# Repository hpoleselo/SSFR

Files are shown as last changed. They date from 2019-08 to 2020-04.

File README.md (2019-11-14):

# Stationary Spinning Follower Robot
A robot that uses fiducial markers (ArUco) to obtain the relative position to the marker and adjusts its position using PID control to follow the moving marker. You can find also separately the modelling of a DC motor which we used on SSFR.

setup

## Installation
Get the Raspberry Pi Ubuntu Mate Installation for your Rpi:
https://ubuntu-mate.org/download/

Install git:

``` $ sudo apt-get install git ```

Install OpenCV with Python in the Rpi in order to make use of the ArUco library:

``` $ sudo apt-get install python-opencv ```

Clone the repository anywhere you want:

``` $ git clone https://github.com/hpoleselo/SSFR.git ```

## Usage

If you want to check how we retrieve the model for the control, check the folder ``` PlantModel ``` with MATLAB.

## Lessons Learned

Check the file [linque] to the next time we decide building a robot from scratch...

## Authors

* **Henrique Poleselo** - [hpoleselo](https://github.com/hpoleselo)
* **Jesse de Oliveira Santana Alves** - [Jessalves11](https://github.com/Jessalves11)
* **Luis Gustavo Nunes Christensen** - [Goustaf](https://github.com/goustaf)

## Professor

**Humberto Xavier de Araujo**

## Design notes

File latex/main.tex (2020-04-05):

\documentclass{article}

\usepackage{arxiv}

\usepackage[utf8]{inputenc} % allow utf-8 input
\usepackage[T1]{fontenc}    % use 8-bit T1 fonts
\usepackage{hyperref}       % hyperlinks
\usepackage{url}            % simple URL typesetting
\usepackage{booktabs}       % professional-quality tables
\usepackage{amsfonts}       % blackboard math symbols
\usepackage{nicefrac}       % compact symbols for 1/2, etc.
\usepackage{microtype}      % microtypography
\usepackage{lipsum}
\usepackage{amsmath}
\usepackage{graphicx}

% Joop Que Recomendou
\geometry{a4paper,right=2.5cm,left=2.5cm,top=3.5cm,bottom=3cm} % margens
\setlength{\parindent}{1cm} % espaçamento do parágrafo
\usepackage{geometry} % configurar layout da página
\usepackage{setspace} % configurar o espaçamento de linhas
\usepackage{indentfirst} % alinhamento do texto, parágrafos

\graphicspath{ {./images/} }
\RequirePackage{amsmath,amsthm,amssymb,hyperref} % Math 
\RequirePackage[brazilian]{babel} % Portugûes

\title{Controle e Modelagem de um Motor de Corrente Contínua - Trabalho de Modelagem e Análise de Sistemas Dinâmicos}

\author{
  Docente: Humberto Xavier de Araújo \\
  \And
  Henrique Nunes Poleselo \\
  %% examples of more authors
   \And
 Jesse de O. S. Alves \\
  \And
  Luis Gustavo Christensen
  %% \AND
  %% Coauthor \\
  %% Affiliation \\
  %% Address \\
  %% \texttt{email} \\
  %% \And
  %% Coauthor \\
  %% Affiliation \\
  %% Address \\
  %% \texttt{email} \\
  %% \And
  %% Coauthor \\
  %% Affiliation \\
  %% Address \\
  %% \texttt{email} \\
}
\begin{document}
\maketitle

\section{Introdução}

O ato de medir a velocidade de uma roda, chamado de odometria, é essencial no campo da robótica móvel, principalmente nos dias atuais, onde o poder de processamento tem aumentado, e portanto, possibilitando a fusão de sensores (odometria com visão computacional, por exemplo) para implementação de controladores mais complexos. Dito isso, a aplicação em questão trata da modelagem e controle de velocidade de um motor de corrente contínua que é acoplado a uma roda. Neste relatório serão apresentados alguns métodos utilizados para a obtenção do modelo caixa preta e o processo de elaboração do controlador.
Deste modo, este trabalho está separado em 8 seções onde cada seção está dividida da seguinte forma: na seção 2 serão mencionados os objetivos do projeto, na seção 3 o protótipo é apresentado. Na seção 4 o processo de modelagem é explicitado, na seção 5, o projeto do controlador do sistema. Na seção 6 os resultados obtidos serão apresentados e em seguida as conclusões do projeto na seção 7. 

\section{Objetivos}
Apesar de utilizar-se os métodos de obtenção de modelo caixa preta, é sabido que a variável velocidade angular de um motor de corrente contínua é um sistema estável. Portanto, o sistema naturalmente chegará ao seu regime permanente para uma entrada degrau. O objetivo da aplicação em questão é fazer com que o motor de corrente contínua atinja esta velocidade angular com um tempo menor utilizando controle PID para reduzir o erro consequentemente.

\section{Descrição do problema}
Para a construção do protótipo utilizou-se apenas um motor de corrente contínua, um Arduino UNO que possui o microcontrolador ATMega328, um sensor (LM393) infravermelho com um fototransistor que gera uma interrupção, um disco de \textit{encoder} e uma ponte H para gerar a corrente necessária para o controle do motor.
A alimentação do motor é dada pela ponte H que recebe um sinal de PWM (\textit{Pulse Width Modulation}) do Arduino e o transmite para o motor com a corrente necessária.
Para obter as curvas da velocidade angular do motor, o disco de \textit{encoder} foi acoplado ao eixo do motor e o sensor infravermelho foi posicionado de modo que este detectasse e gerasse uma interrupção toda vez em que o feixe de onda eletromagnética atravessasse um buraco do disco. Dessa forma, é possível medir a frequência com que o disco gira e utilizando o raio da roda determinar a velocidade angular do mesmo ao longo do tempo. Essas medições realizadas com o sensor foram validadas através de uma marcação na roda e determinação da velocidade linear que posteriormente foi dividida pelo raio da roda, e percebeu-se que o sensor apresenta distorções para rotações altas (próximas a 120 bits de PWM), além de apresentar medições relativamente ruidosas.

Para a leitura da velocidade, fez-se como descrito acima e a montagem pode ser vista na figura 1:
\begin{center}
\centering
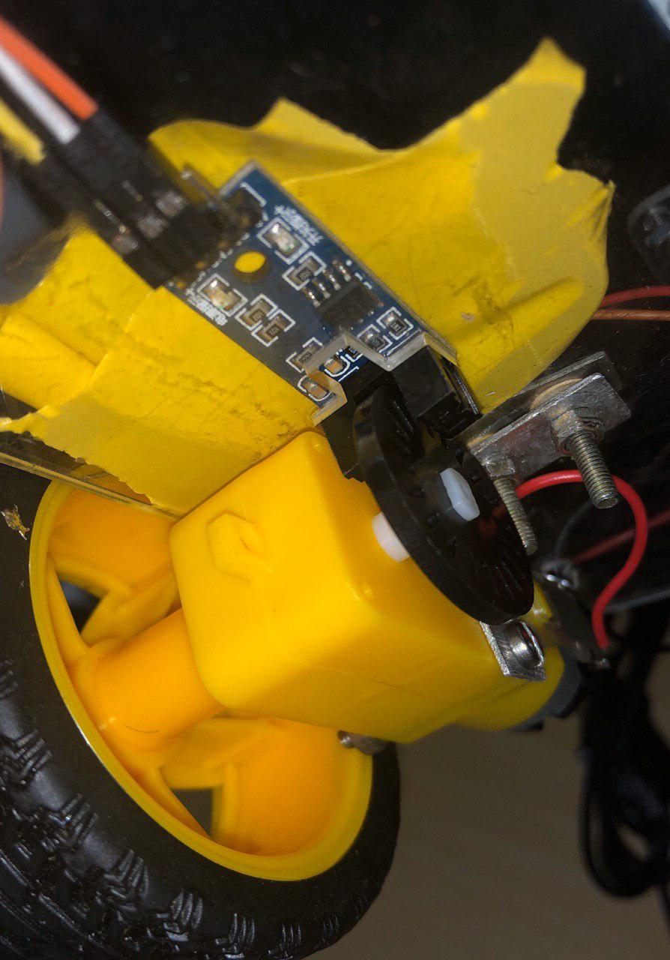
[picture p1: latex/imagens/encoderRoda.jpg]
  
  
  \caption{Figura 1: Montagem para leitura da velocidade da roda.}
\end{center}

As rodas foram acopladas à uma base podendo servir futuramente como um robô. Na seção 4 a modelagem do motor é feita com o robô suspenso, portanto desprezando atrito dinâmico e considerando apenas o atrito estático do próprio motor e da roda. A montagem final pode ser vista na figura 2.

\begin{center}
\centering
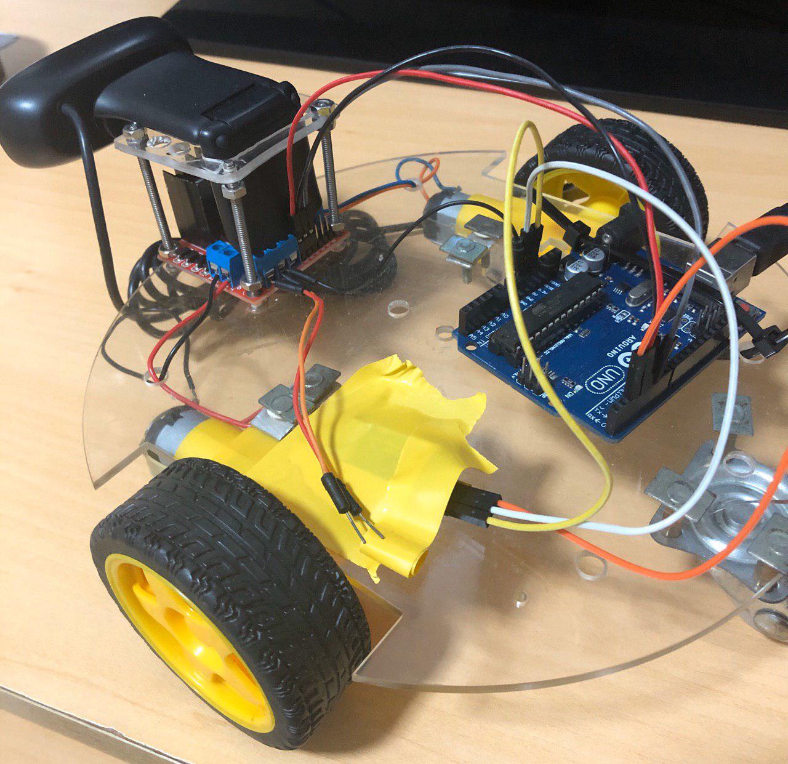
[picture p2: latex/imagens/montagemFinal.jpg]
  
  
  \caption{Figura 2: Protótipo montado.}
\end{center}

\section{Modelagem}

\subsection{Modelo Estático}
Para ter um bom ponto de partida parta a modelagem do sistema, obteve-se a curva do comportamento estático do sistema. Tal curva é importante para determinar a faixa de valores de PWM na qual o sistema responda da forma mais linear, facilitando assim o controle do processo.
Para determinar qual a faixa de operação do PWM, foi aplicado por meio do microcontrolador diferentes valores (de 0 a 255, faixa de 8 bits) e analisou-se que a zona morta do motor se situava na faixa de 0 a 60 bits do PWM, portanto, assumiu-se que a faixa de operação para o controlador seria de no mínimo 6O bits do PWM. O modelo estático foi proposto com a variação do PWM entre 75 e 255 bits pois é a faixa em que o motor opera com segurança.

\begin{center}
\centering
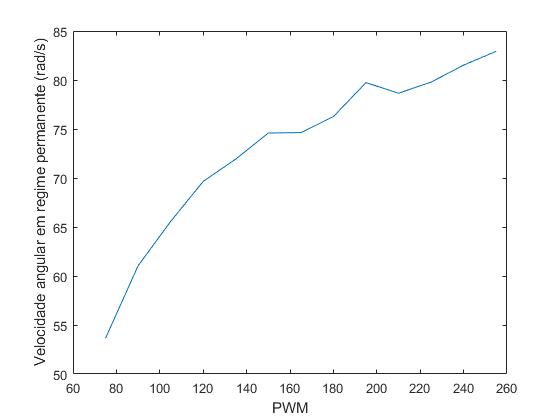
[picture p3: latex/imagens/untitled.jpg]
  
  
  \caption{Figura 3: Modelo estático do motor de corrente contínua.}
\end{center}

A partir da figura 3 é possível notar que na faixa entre 90 e 145 PWM há um comportamento aproximadamente linear, logo é desejável trabalhar com valores contidos nesse intervalo.

\subsection{Modelo Dinâmico}
O modelo dinâmico apresenta a relação entre a entrada e a saída do sistema no regime transitório e permanente. Tal comportamento é obtido a partir de uma entrada degrau, que na aplicação é um "nível DC" do PWM, portanto tensão.
Assim como no modelo estático, a entrada será o valor do PWM e a saída será a velocidade angular da roda. Foi escolhido 120 como valor de PWM já que este se encontra no intervalo em que o sistema mostrou um comportamento linear no modelo estático. Na Figura 4, utilizando a lógica mencionada na seção 3, obteve-se a velocidade angular instantânea da roda com um tempo de amostragem de $50ms$.

\begin{center}
\centering
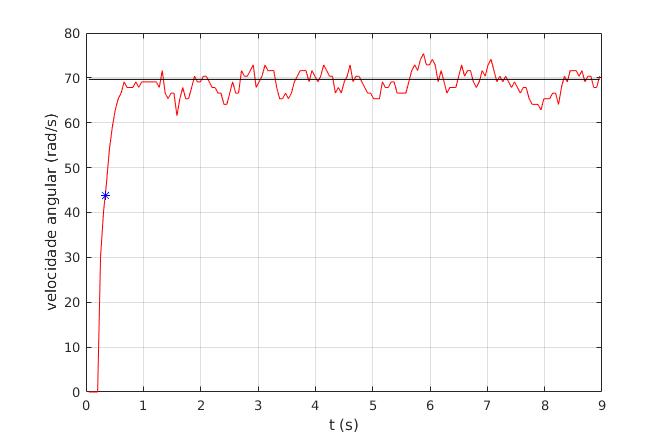
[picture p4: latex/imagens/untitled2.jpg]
  
  
  \caption{Figura 4: Modelo dinâmico do motor de corrente contínua.}
\end{center}

Pela figura 4 é possível ver uma zona morta até o sistema responder, tal fenômeno é devido ao filtro média móvel aplicado posteriormente aos dados da velocidade adquiridos. Viu-se a necessidade de usar filtragem já que o sensor não oferece tanta robustez para altas velocidades. Como no controle optou-se por não usar o filtro média móvel, é possível desprezar a zona morta em questão. No entanto, obteve-se diferentes modelos para efeitos de comparação. A entrada degrau utilizada na figura 4 foi de 120 bits PWM e como é possível inferir pelo gráfico o $y({\infty}) = 69.66 rad/s$  (regime permanente), portanto condizendo com o modelo estático proposto na seção 4.1.

\subsection{Modelo a Dois Parâmetros}
O primeiro modelo proposto foi o de dois parâmetros, o qual utiliza o ganho (K) e a constante de tempo (T) da seguinte forma [1]:

\begin{equation}
    G(s) = \frac{K}{T \cdot s + 1}.
\end{equation}

Como sabe-se que $y({\infty}) = 69.66 rad/s$ e a entrada é um PWM de 120 bits, que equivale a $u(t)$ com amplitude de $4.92V$, logo o valor de K é 14.16, que é a divisão entre $y({\infty})$ e a entrada degrau. Para encontrar a constante de tempo, utilizou-se o método da área entre a reta que representa o regime permanente menos a curva de regime transitório [2]. Com o valor da área obtido, o valor de $T$ é encontrado por $T=Ao/k$, onde $Ao$ é a área e $k$ o ganho, portanto $T = 0.2571$. Então:

\begin{equation}
    G(s) = \frac{14.16}{0.2571 \cdot s + 1}.
\end{equation}

\subsection{Modelo a Três Parâmetros}
No modelo a três parâmetros, além de utilizar o ganho e a constante de tempo, levou-se em conta o atraso $L$ do sistema, de modo a obter o seguinte modelo:

\begin{equation}
    G(s) = \frac{K \cdot e^{-L \cdot s\!}}{T \cdot s + 1}.
\end{equation}

O ganho se mantém o mesmo $K = 14.1585$ e o valor do atraso é igual ao valor de tempo morto $L = 0.153 s$. Com o valor do atraso e o valor do ganho, obtém-se a constante de tempo de modo análogo ao obtido com o modelo a dois parâmetros, no entanto considerando o atraso:

\begin{equation}
    T = \frac{Ao}{K} - {L}
\end{equation}

Desse modo, obteve-se $T = 0.1045 s$. Logo o modelo ficou da seguinte forma:

\begin{equation}
    G(s) = \frac{14.1585 \cdot e^{-0.153 \cdot s\!}}{0.1045 \cdot s + 1}
\end{equation}

Utilizando a aproximação linear de Padé(0,1) obteve-se a seguinte função de transferência:

\begin{equation}
    G(s) = \frac{14.1585}{0.0159 \cdot s^{2\!} + 0.2571 \cdot s + 1}
\end{equation}

\subsection{System Identification Toolbox}
Além dos modelos obtidos acima, utilizou-se a \textit{toolbox} do MATLAB \textit{System Identification}, na qual utiliza os dados de saída e entrada para a obtenção do modelo.

Com 2 pólos e zeros infinitos:
\begin{equation}
    G(s) = \frac{1186}{s^{2\!} + 16.49 \cdot s + 84.71}
\end{equation}

Com 1 pólo e zeros infinitos:
\begin{equation}
    G(s) = \frac{65.36}{s + 4.656}
\end{equation}

Utilizando a função \textit{step} às funções de transferência (2), (6), (7) e (8) foi obtida a resposta ao degrau de $4.92V$:

\begin{center}
\centering
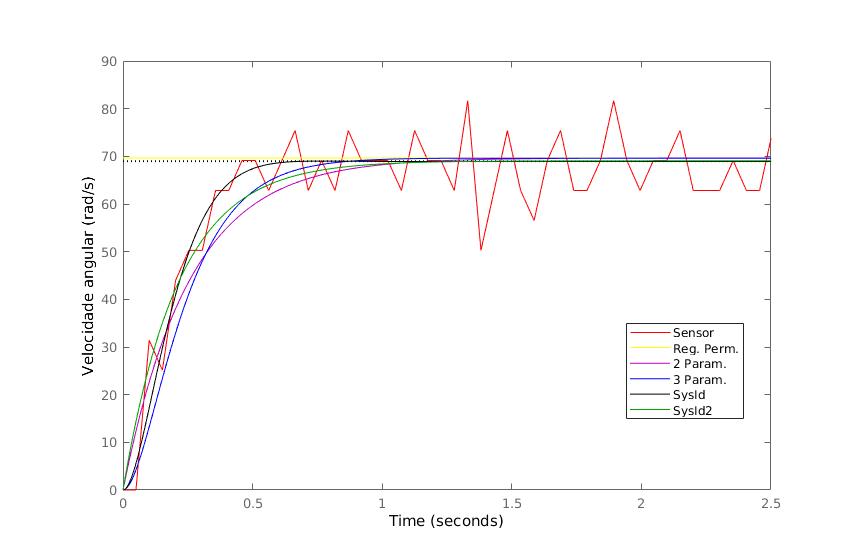
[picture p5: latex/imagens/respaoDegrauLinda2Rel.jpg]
  
  
  \caption{Figura 5: Gráfico para diferentes aproximações da função de transferência do motor.}
\end{center}

Vale notar que o filtro média móvel foi retirado de forma a tirar o atraso e poder comparar as curvas de forma mais fidedigna. Uma boa métrica para escolher as melhores funções de transferência seria calculando o erro entre a curva experimental (vermelha) e as respectivas funções aproximadas e ver qual possuí o menor erro. Infelizmente não houve tempo durante o experimento realizado para tal, portanto foi utilizada a métrica de quais curvas parecem mais se aproximar da vermelha, que são as curvas rosa e azul, respectivamente, as aproximações (2) e (3).
Para validar as escolhas feitas foi simulado na ferramenta \textit{Simulink} todas as funções aproximadas e com o critério de Routh para estabilidade testou-se os ganhos $Kp$, $Ki$ e $Kd$ para ver como os sistemas se comportavam em malha fechada. No final das contas, o próprio $Simulink$ conta com um atalho para à ferramenta \textit{PID Tuner}, que busca ganhos que provém robustez ao sistema (rejeição de ruído e seguimento de referência), portanto utilizando a ferramenta viu-se que os modelos escolhidos conseguiam prover uma boa resposta, como será visto mais a frente.

\section{Projeto do Controlador}
Como foram escolhida duas aproximações para o sistema, propõe-se dois controladores. Portanto, foi calculada a função de transferência em malha fechada da aproximação (2):

\begin{equation}
    \frac{Y(s)}{R(s)} = \frac{s^{2\!} \cdot {14.1585 \cdot Kd} + s \cdot {14.1585 \cdot Kp} + {14.1585 \cdot Ki}}{s^{2\!} \cdot {(0.2517+14.1585 \cdot Kd)} + s \cdot {(14.1585 \cdot Kp + 1)} + {14.1585 \cdot Ki}}
    \end{equation}
    
    Aplicando o critério de Routh para obter o intervalo em que os ganhos do controlador geram um sistema estável, foi obtido $Kd > -0.0178$, $Kp > -0.0706$ e $Ki > 0$. Sabendo o intervalo de valores em que os ganhos devem estar contidos. Como mencionado anteriormente, foi simulado \textit{PID Tuner} juntamente com o \textit{Simulink} para obter os ganhos com certa robustez para o controlador, sendo tais ganhos: $Kp = 0.094472$, $Ki = 0.734462$ e $Kd = -0.000882$ onde todos os ganhos obedecem às condições impostas pelo critério de Routh, portanto estes foram utilizados no projeto do PID. Portanto, a função de transferência ficou da seguinte forma:
    
    \begin{equation}
    \frac{Y(s)}{R(s)} = \frac{s^{2\!} \cdot {-0.0125} + s \cdot {1.3376} + {10.3989}}{s^{2\!} \cdot {0.2392} + s \cdot {2.3376} + {10.3989}}
    \end{equation}
    
    A função de transferêcia obtida a curva conforme a figura 6:
    
    \begin{center}
    \centering
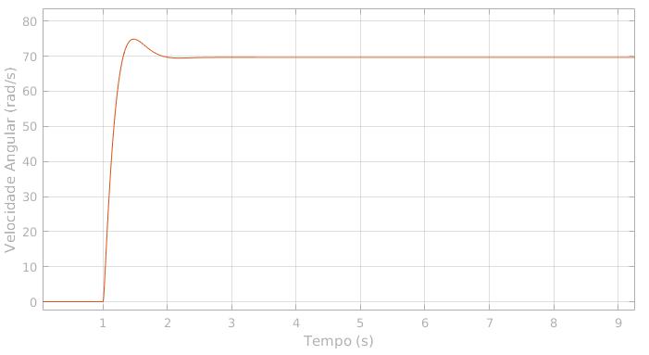
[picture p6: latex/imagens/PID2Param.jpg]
        
        
        \caption{Figura 6: Resposta do sistema (2) em malha fechada com controlador PID no Simulink.}
    \end{center}
    
    Ao fazer o procedimento análogo ao último porém com o modelo a três parâmetros, foi observado que o \textit{PID Tuner} do MATLAB retornou valores dos ganhos no PID que resultaram num sinal de controle inviável fisicamente (saturação), ao remover o ganho derivativo foi observado que o sinal de controle se tornou viável de ser gerado, portanto foi decidido utilizar um controlador PI nesse caso. Ao fechar a malha do controlador PI com o modelo a três parâmetros (6), foi obtido a seguinte função de transferência:
    
    \begin{equation}
    \frac{Y(s)}{R(s)} = \frac{s \cdot {14.1585 \cdot Kp} +  {14.1585 \cdot Ki}}{s^{3\!} \cdot {0.016} s^{2\!} \cdot {0.26} + s \cdot {(14.1585 \cdot Kp + 1)} + {14.1585 \cdot Ki}}
    \end{equation}
    
    Realizando novamente o critério de Routh, obteve-se os seguintes intervalos dos ganhos $Kp > -0.07$ e $0 < Ki < Kp + 17.26$. Como os ganhos que a ferramenta \textit{PID Tuner} retornou estão contidos nesse intervalo, os mesmos foram utilizados sendo $Kp = 0.1341$ e $Ki = 0.7349$. Desta forma obteve-se a seguinte função de transferência em malha fechada:
    
     \begin{equation}
    \frac{Y(s)}{R(s)} = \frac{s \cdot {1.8987} +  {10.4051}}{s^{3\!} \cdot {0.016} + s^{2\!} \cdot {0.26} + s \cdot {2.8987} + {10.4051}}
    \end{equation}
    
    A função de transferência obtida gerou a seguinte curva:
    
    \begin{center}
    \centering
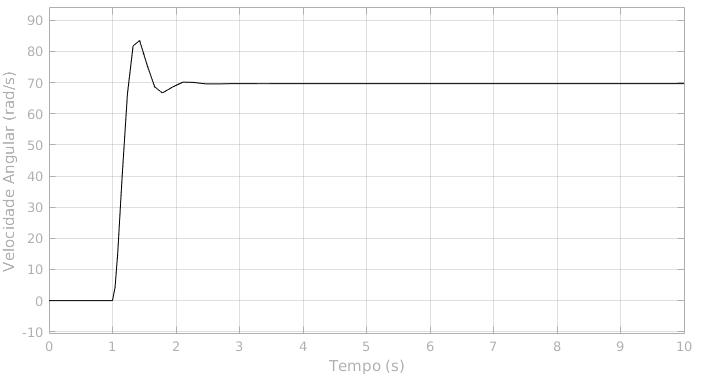
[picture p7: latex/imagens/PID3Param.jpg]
        
        
        \caption{Figura 7: Resposta do sistema (6) em malha fechada com controlador PI no Simulink }
    \end{center}
    
    Os ganhos "ótimos" retornados pelo \textit{PID Tuner} foram: (consequentemente os usados nos experimentos)
    \begin{center}
    \begin{tabular}{|c|c|c|c|c|}
            \hline
            Modelo & $Kp$ & $Ki$ & $Kd$ & Controlador \\
            \hline
            (2) & 0.094471 &  0.73446 & -0.000882 & 1 \\
            \hline
            (6) & 0.134078, & 0.73489 & 0 & 2 \\
            \hline
    \end{tabular}
    
  \caption{Quadro 1}
\end{center}

    \begin{table}
\begin{tabular}
...
\end{tabular}
\caption{\label{tab:table-name}Your caption.}
\end{table}

\section{Resultados experimentais}

Para melhor avaliar os controladores propostos é interessante avaliar qual controlador provê o menor erro, portanto uma boa métrica para se utilizar é o \textit{Integral of the Square of the Error} ou ISE, é basicamente elevar cada elemento do vetor erro ao quadrado depois soma-los [3].

\begin{center}
    \begin{tabular}{|c|c|c|c|}
            \hline
            PWM (bits) & $ISE$ (rad^2/s^2) & Controlador & Modelo \\
            \hline
            120 & $9.3345*10^4$ & Não & X \\
            \hline
            75 & $8.7627*10^4$ & Não & X \\
            \hline
            120 & $8.8662*10^4$ & 1 & (2) \\
            \hline
            75 & $1.0561*10^4$ & 1 & (2)\\
            \hline
            120 & $1.0534*10^5$ & 2 & (6) \\
            \hline
            75 & $9.9548*10^3$ & 2 & (6)\\
            \hline
    \end{tabular}
    
  \caption{Quadro 2}
\end{center}

Pelo Quadro 1 infere-se que o melhor controlador foi o PID com o modelo a três parâmetros, pois apresentou o menor erro. É interessante notar que para alta velocidade (alto PWM) as medidas começam a ter muita inconsistência e portanto mesmo com o controlador o erro não diminui, isso deve-se principalmente ao sensor.

Para tentar melhor avaliar o controlador adicionou-se um distúrbio ao sistema de forma a tirar o mesmo de sua referência, novamente usou-se como métrica o $ISE$:

\begin{center}
    \begin{tabular}{|c|c|c|}
            \hline
            PWM (bits) & ISE (rad^2/s^2) & Controlador \\
            \hline
            120 & $1.2112*10^5$ & 1 \\
            \hline
            75 & $2.6285*10^4$ & 1\\
            \hline
            120 & $1.3101*10^5$ & 2\\
            \hline
            75 & $2.4900*10^4$ & 2\\
            \hline
    \end{tabular}
    
  \caption{Quadro 3}
\end{center}

Outra métrica para analisar se a presença do controlador nesse sistema é desenhar os gráficos da velocidade do motor com a roda quando: não há controlador, com o controlador, com o controlador com distúrbio externo, assim fez-se para o PWM de 120 bits, i.e referência de $59.66rad/s$:

\begin{center}
    \centering
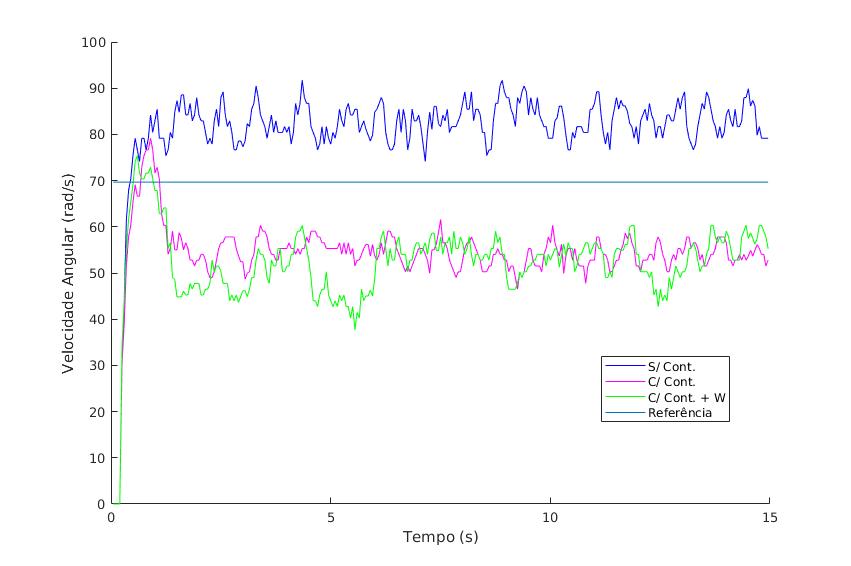
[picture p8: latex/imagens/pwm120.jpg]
        
        
        \caption{Figura 8: Resposta do sistema sem controlador, com controlador e com controlador + distúrbio }
\end{center}

\begin{center}
    \centering
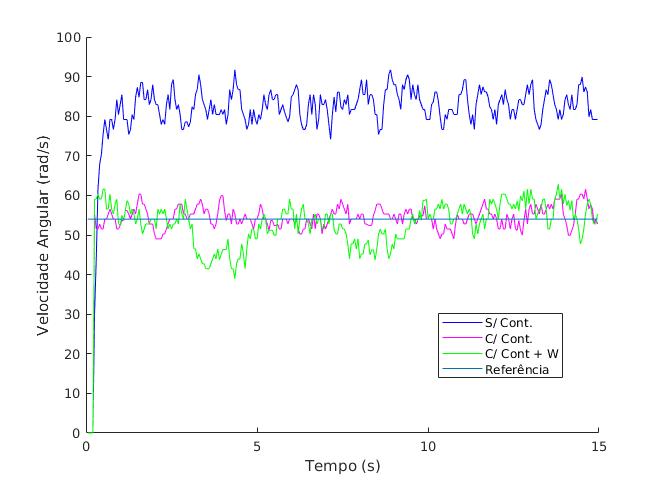
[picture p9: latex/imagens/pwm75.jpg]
        
        
        \caption{Figura 9: Resposta do sistema sem controlador, com controlador e com controlador + distúrbio }
\end{center}

Quando a velocidade da roda é menor (54 rad/s) faz com que o sensor consiga trabalhar em uma faixa melhor, portanto é infere-se da figura 9 que a curva rosa de fato fica em torno da referência (reta azul), e mesmo com distúrbios ao sistema (curva em verde) o mesmo fica em torno da referência. Percebe-se que a falta do controlador de fato faz diferença, já que a curva em azul está totalmente fora da referência.

Já com a velocidade maior (com 69.66 rad/s) ou 120 bits de PWM percebe-se que há muitos erros associados às medidas, resultando na velocidade de referência estar completamente distoante da velocidade real, seja com o o controlador ou sem.

\section{Conclusão}
Após as leituras dos dados experimentais e obtenção de dois modelos, juntamente com a variação do PWM entre os valores de 120 e 75 bits, percebe-se que quanto maior o sinal de PWM maior são os erros,i.e , em altas velocidades ocorrem problemas de precisão na leitura dos sensores. Além de que o modelo a dois parâmetros com um PWM de 75 bits fornece o menor erro quadrátio e isso se deu pelo fato de estar em rotações mais baixas e do ganho $Kd$ ser diferente de zero (somente no modelo a dois parâmetros), fazendo-o responder mais rapidamente.

Os códigos tanto para os cálculos analíticos quanto o da implementação da lógica do controlador no Arduino podem ser encontrados no seguinte link: \url{https://github.com/hpoleselo/ssfr}

\bibliographystyle{unsrt}  
%\bibliography{references}  %%% Remove comment to use the external .bib file (using bibtex).
%%% and comment out the ``thebibliography'' section.

%%% Comment out this section when you \bibliography{references} is enabled.
\begin{thebibliography}{1}
\bibitem{hadash2018estimate}
Control System Design by Karl Johan Aestroem

\bibitem{kour2014real}
Código Fonte MATLAB, Autoria Própria.
\newblock https://github.com/hpoleselo/SSFR/tree/master/PlantModel/WheelModel.

\bibitem{kour2014fast}
\newblock Dorf, R. C.; Bishop, R. h. Sistemas de Controle Moderno. 5a edição

\end{thebibliography}

\end{document}

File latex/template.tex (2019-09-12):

\documentclass{article}

\usepackage{arxiv}

\usepackage[utf8]{inputenc} % allow utf-8 input
\usepackage[T1]{fontenc}    % use 8-bit T1 fonts
\usepackage{hyperref}       % hyperlinks
\usepackage{url}            % simple URL typesetting
\usepackage{booktabs}       % professional-quality tables
\usepackage{amsfonts}       % blackboard math symbols
\usepackage{nicefrac}       % compact symbols for 1/2, etc.
\usepackage{microtype}      % microtypography
\usepackage{lipsum}
\RequirePackage{amsmath,amsthm,amssymb,hyperref} % Math 
\RequirePackage[brazilian]{babel} % Portugûes

\title{A template for the \emph{arxiv} style}

\author{
  David S.~Hippocampus\thanks{Use footnote for providing further
    information about author (webpage, alternative
    address)---\emph{not} for acknowledging funding agencies.} \\
  Department of Computer Science\\
  Cranberry-Lemon University\\
  Pittsburgh, PA 15213 \\
  \texttt{hippo@cs.cranberry-lemon.edu} \\
  %% examples of more authors
   \And
 Elias D.~Striatum \\
  Department of Electrical Engineering\\
  Mount-Sheikh University\\
  Santa Narimana, Levand \\
  \texttt{stariate@ee.mount-sheikh.edu} \\
  %% \AND
  %% Coauthor \\
  %% Affiliation \\
  %% Address \\
  %% \texttt{email} \\
  %% \And
  %% Coauthor \\
  %% Affiliation \\
  %% Address \\
  %% \texttt{email} \\
  %% \And
  %% Coauthor \\
  %% Affiliation \\
  %% Address \\
  %% \texttt{email} \\
}

\begin{document}
\maketitle

\begin{abstract}
\lipsum[1]
\end{abstract}

% keywords can be removed
\keywords{First keyword \and Second keyword \and More}

\section{Introduction}
\lipsum[2]
\lipsum[3]

\section{Headings: first level}
\label{sec:headings}

\lipsum[4] See Section \ref{sec:headings}.

\subsection{Headings: second level}
\lipsum[5]
\begin{equation}
\xi _{ij}(t)=P(x_{t}=i,x_{t+1}=j|y,v,w;\theta)= {\frac {\alpha _{i}(t)a^{w_t}_{ij}\beta _{j}(t+1)b^{v_{t+1}}_{j}(y_{t+1})}{\sum _{i=1}^{N} \sum _{j=1}^{N} \alpha _{i}(t)a^{w_t}_{ij}\beta _{j}(t+1)b^{v_{t+1}}_{j}(y_{t+1})}}
\end{equation}

\subsubsection{Headings: third level}
\lipsum[6]

\paragraph{Paragraph}
\lipsum[7]

\section{Examples of citations, figures, tables, references}
\label{sec:others}
\lipsum[8] \cite{kour2014real,kour2014fast} and see \cite{hadash2018estimate}.

The documentation for \verb+natbib+ may be found at
\begin{center}
  \url{http://mirrors.ctan.org/macros/latex/contrib/natbib/natnotes.pdf}
\end{center}
Of note is the command \verb+\citet+, which produces citations
appropriate for use in inline text.  For example,
\begin{verbatim}
   \citet{hasselmo} investigated\dots
\end{verbatim}
produces
\begin{quote}
  Hasselmo, et al.\ (1995) investigated\dots
\end{quote}

\begin{center}
  \url{https://www.ctan.org/pkg/booktabs}
\end{center}

\subsection{Figures}
\lipsum[10] 
See Figure \ref{fig:fig1}. Here is how you add footnotes. \footnote{Sample of the first footnote.}
\lipsum[11] 

\begin{figure}
  \centering
  \fbox{\rule[-.5cm]{4cm}{4cm} \rule[-.5cm]{4cm}{0cm}}
  \caption{Sample figure caption.}
  \label{fig:fig1}
\end{figure}

\subsection{Tables}
\lipsum[12]
See awesome Table~\ref{tab:table}.

\begin{table}
 \caption{Sample table title}
  \centering
  \begin{tabular}{lll}
    \toprule
    \multicolumn{2}{c}{Part}                   \\
    \cmidrule(r){1-2}
    Name     & Description     & Size ($\mu$m) \\
    \midrule
    Dendrite & Input terminal  & $\sim$100     \\
    Axon     & Output terminal & $\sim$10      \\
    Soma     & Cell body       & up to $10^6$  \\
    \bottomrule
  \end{tabular}
  \label{tab:table}
\end{table}

\subsection{Lists}
\begin{itemize}
\item Lorem ipsum dolor sit amet
\item consectetur adipiscing elit. 
\item Aliquam dignissim blandit est, in dictum tortor gravida eget. In ac rutrum magna.
\end{itemize}

\bibliographystyle{unsrt}  
%\bibliography{references}  %%% Remove comment to use the external .bib file (using bibtex).
%%% and comment out the ``thebibliography'' section.

%%% Comment out this section when you \bibliography{references} is enabled.
\begin{thebibliography}{1}

\bibitem{kour2014real}
George Kour and Raid Saabne.
\newblock Real-time segmentation of on-line handwritten arabic script.
\newblock In {\em Frontiers in Handwriting Recognition (ICFHR), 2014 14th
  International Conference on}, pages 417--422. IEEE, 2014.

\bibitem{kour2014fast}
George Kour and Raid Saabne.
\newblock Fast classification of handwritten on-line arabic characters.
\newblock In {\em Soft Computing and Pattern Recognition (SoCPaR), 2014 6th
  International Conference of}, pages 312--318. IEEE, 2014.

\bibitem{hadash2018estimate}
Guy Hadash, Einat Kermany, Boaz Carmeli, Ofer Lavi, George Kour, and Alon
  Jacovi.
\newblock Estimate and replace: A novel approach to integrating deep neural
  networks with existing applications.
\newblock {\em arXiv preprint arXiv:1804.09028}, 2018.

\end{thebibliography}

\end{document}

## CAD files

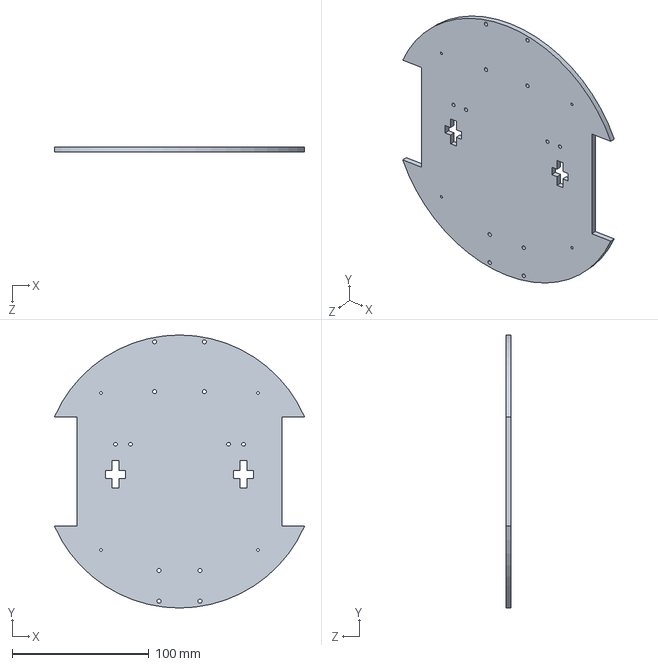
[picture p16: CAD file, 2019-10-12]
3DModels/BaseInferior.SLDPRT
183.3 x 200.0 x 4.00 mm

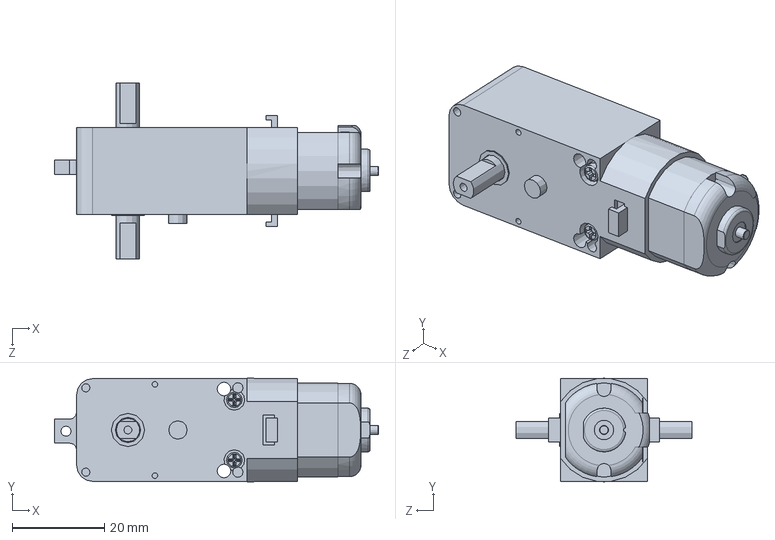
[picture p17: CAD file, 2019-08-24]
3DModels/MotorRedutor.SLDPRT
70.3 x 22.5 x 38.2 mm

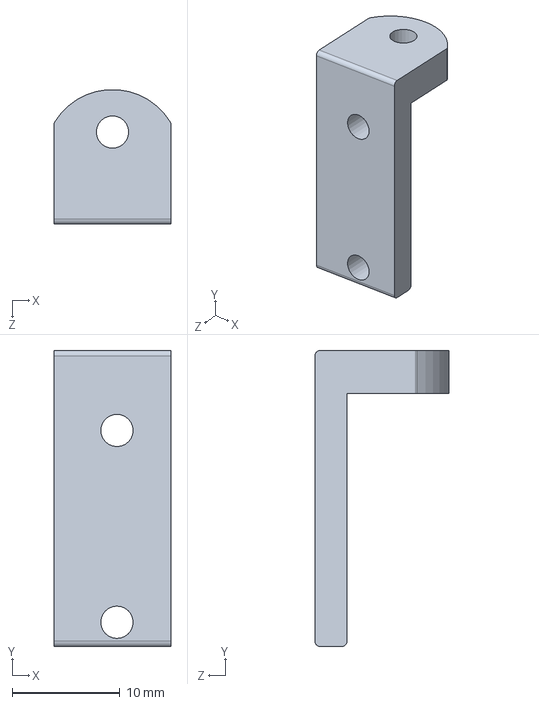
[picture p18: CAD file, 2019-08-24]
3DModels/SuporteMotor.SLDPRT
10.8 x 27.5 x 12.5 mm

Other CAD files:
3DModels/TransferidorFinal.SLDPRT
3DModels/BaseInferior.DXF
3DModels/SuporteMotor.STL
3DModels/TransferidorFinal.DXF

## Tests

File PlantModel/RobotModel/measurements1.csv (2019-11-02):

t | phi1
0 | 0.0000000000
40 | 23.5620002746
81 | 47.1240005493
122 | 7.8539996147
163 | 15.7079992294
204 | 7.8539996147
245 | 7.8539996147
286 | 133.5179901123
327 | 39.2700004577
368 | 39.2700004577
409 | 7.8539996147
450 | 31.4159984588
491 | 47.1240005493
532 | 7.8539996147
573 | 15.7079992294
614 | 15.7079992294
655 | 23.5620002746
696 | 15.7079992294
737 | 117.8099899291
778 | 31.4159984588
819 | 23.5620002746
860 | 133.5179901123
901 | 31.4159984588
942 | 7.8539996147
983 | 102.1019973754
1024 | 54.9780006408
1065 | 7.8539996147
1107 | 15.7079992294
1148 | 23.5620002746
1189 | 109.9560012817
1230 | 47.1240005493
1271 | 15.7079992294
1312 | 70.6859970092
1353 | 102.1019973754
1394 | 31.4159984588
1435 | 7.8539996147
1476 | 31.4159984588
1517 | 23.5620002746
1558 | 23.5620002746
1599 | 47.1240005493
1640 | 102.1019973754
1681 | 31.4159984588
1722 | 86.3939971923
1763 | 188.4960021972
1804 | 23.5620002746
1845 | 23.5620002746
1886 | 15.7079992294
1927 | 23.5620002746
1968 | 31.4159984588
2009 | 31.4159984588
2050 | 23.5620002746
2091 | 117.8099899291
2132 | 125.6639938354
2174 | 62.8319969177
2216 | 7.8539996147
2257 | 15.7079992294
2298 | 47.1240005493
2339 | 39.2700004577
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

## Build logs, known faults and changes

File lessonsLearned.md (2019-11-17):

# Lessons Learned

First of all, check the deadband from the motor. We tested our motor with ~2V and it was spinning. Note that when you add the motor
to your robot the deadband will increase due to the robot's weight, so expect the motor to work around 2.5V, for instance. The ideal
would be have our robot operating with very low voltage so it can do fine adjustments, i.e our controller would work better.

## Physical Part
- Check deadband
- Check the sensor you want to use to control the feedback of your robot
- Find the minimum voltage that the robot responds, this will be important for your controller
- When you build your robot the wheels should be SYMMETRICAL, otherwise the robot will not go forward or rotate on its on axis properly
- After mounting the wheels on the robot don't forget to test with simple functions like going forward and check if they're really symmetrical

## Control
- Check if the actuator speed is at least 3x faster than the response of your sensor
- In order to the controller work properly the sensor should deliver AT LEAST 25Hz samples to have a closed loop control w/ that sensor
- After checking the minimum voltage you know your dynamic range to control
- The higher the dynamic range the better because you could do fine adjustments

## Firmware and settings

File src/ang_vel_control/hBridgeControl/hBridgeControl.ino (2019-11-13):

// Code from PID: https://gist.github.com/ivanseidel/b1693a3be7bb38ff3b63
// Creating the PID as an object to be instantiated on our main code
class PID{
public:
  
  double error;
  double sample;
  double lastSample;
  double kP, kI, kD;      
  double P, I, D;
  double pid;
  
  double setPoint;
  long lastProcess;
  
  PID(double _kP, double _kI, double _kD){
    kP = _kP;
    kI = _kI;
    kD = _kD;
  }

  // Add new sample is basically reading from the sensor the variable, in our case the velocity
  void addNewSample(double _sample){
    sample = _sample;
  }

  // Gets new variable
  void setSetPoint(double _setPoint){
    setPoint = _setPoint;
  }
  
  double process(){
    // Implementação PID
    error = setPoint - sample;
    float deltaTime = (millis() - lastProcess) / 1000.0;
    lastProcess = millis();
    
    //P
    P = error * kP;
    
    //I
    I = I + (error * kI) * deltaTime;
    
    //D
    D = (lastSample - sample) * kD / deltaTime;
    lastSample = sample;
    
    // Soma tudo
    pid = P + I + D;
    
    return pid;
  }
};

// This is the value of the PWM we used to retrieve the experimental curve, is the point where we want to operate
const float steadyStatePWM = 120.0;
const float steadyStateSpeed = 69.66;

// Another point of operation (reference), if we want to add the new reference, change the flag to TRUE
const float secondSteadyStatePWM = 75;
const float secondSteadyStateSpeed = 54.0; // rad/s from the static model
bool addAnotherReference = true;

// Variable used to send the signal from the PID to our actuator, in this case, the motor.
float controlPWM = 0;

// Pins for connecting Arduino w/ Motor
int IN1 = 4 ;
int IN2 = 5 ;
int motorSpeed = 3;
int D0IN = 2; // Encoder pin

// Variables to calculate the velocity
int rpm;
volatile byte pulses;
unsigned long timeold;
unsigned long actual_time;
float phi;
float error;
unsigned int pulsesPerRound = 20;   // How many holes one complete rotation in our encoder has
int sampleTime = 50;                // In miliseconds

// Gains of the PID Controller
// 2 parametros
//double Kp = 0.094471, Ki = 0.73446, Kd = -0.000882;

// 3 parametros com atraso com PID Tuner
double Kp = 0.134078, Ki = 0.73489, Kd = 0.00518;

// Instantiating our PID controller
PID SpeedPidControl(Kp,Ki,Kd);

// ISR
void counter()
{
  // Everytime we detect a hole it counts as one pulse, pulses = pulses + 1
  pulses++;
  
}

void setup(){
    pinMode(IN1,OUTPUT);
    pinMode(IN2,OUTPUT);
    pinMode(motorSpeed,OUTPUT);

    // Sets up the motor to go forward by default
    digitalWrite(IN1,HIGH);
    digitalWrite(IN2,LOW);
  
    Serial.begin(9600);
    // The pin has be our input since we're reading the pulses from the sensor
    pinMode(D0IN, INPUT);
    //Interrupcao 0 - pino digital 2
    // Everytime the interrupt is triggered (borda de descida) we call the counter
    attachInterrupt(0, counter, FALLING);
    pulses = 0;
    rpm = 0;
    timeold = 0;
}

void loop(){

  // PWM goes from 0 to 255, 255 is the full Duty Cycle

  // millis() returns the number of milliseconds passed since the Arduino board began running the current program
  // Runs for 30s, 15s in one reference and 15s in another reference
  while (millis() <= 30000) {
        // Sample time is set to
        if (millis() - timeold >= sampleTime) {
          // Disables Interrupt while doing calculation
          detachInterrupt(0);

          // Pulses is always 1 because we set it to 0 in the end of the code, it is like a flag that we're detecting something
          // otherwise it will not calculate the speed of the wheel
          rpm = ((60 * 1000 / pulsesPerRound ) / (millis() - timeold)) * pulses;
          actual_time = millis();
          
          // Convert to angular velocity to feed the model
          phi = (3.1416*rpm)/30;
          
          // Pass the read variable to the PID controller
          SpeedPidControl.addNewSample(phi);
          
          timeold = millis();
          pulses = 0;
          
          attachInterrupt(0, counter  , FALLING);

          // Reference for our PID is 120, as the model we retrieved
          if (millis() <= 14999) {
            
              // Calculate the error so we can compare with other methods
              error = phi - steadyStateSpeed;
              
              // PID signal control to our actuator, calculates the error and so on
              controlPWM = (SpeedPidControl.process() + steadyStatePWM);
    
              // If our PID controller tries to subceed the minimum to rotate the motor...
              if (controlPWM < 60) {
                //Serial.println("Tentou colocar menos no motor");
                controlPWM = 60;
              }
              
              // If our PID controller tries to surpass the limit
              else if (controlPWM > 255) {
                //Serial.println("Tentou colocar mais no motor");
                controlPWM = 255;
              }
              // Actuate on motor based on the output from the PID
              analogWrite(motorSpeed,controlPWM);
          }


          // Just enters in this condition if we want to add another reference
          if (addAnotherReference == true and (millis() >= 15000)) {
              error = phi - secondSteadyStateSpeed;
              
              // PID signal control to our actuator, calculates the error and so on
              controlPWM = (SpeedPidControl.process() + secondSteadyStatePWM);
    
              // If our PID controller tries to subceed the minimum to rotate the motor...
              if (controlPWM < 60) {
                //Serial.println("Tentou colocar menos no motor");
                controlPWM = 60;
              }
              
              // If our PID controller tries to surpass the limit
              else if (controlPWM > 255) {
                //Serial.println("Tentou colocar mais no motor");
                controlPWM = 255;
              }
              // Actuate on motor based on the output from the PID
              analogWrite(motorSpeed,controlPWM);
            
          }
          // Print in the csv format
          //Serial.print(actual_time);
          //Serial.print(",");
          Serial.print(phi, DEC);
          Serial.print(",");
          Serial.println(error);     

          
        }
  }
}

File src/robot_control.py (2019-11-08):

import RPi.GPIO as GPIO
import sys
import rospy
import pidcontroller
import threading
import csv
#import pi_aruco_interface
from time import sleep, time
from geometry_msgs.msg import Point

class FollowerRobot(object):
    def __init__(self, use_ros=True):
        """ This init function sets the Raspberry ports to control the H-Bridge and initializes the ArUco interface """
        en = 25     # PWM port
        enb = 17    # PWM2 port

        self.in1 = 24    # Motor A forward direction control
        self.in2 = 23    # Motor A backwards direction control

        # Escolhemos duas GPIOs proximas da do Motor A, aleatorio
        self.inB1 = 22   # Motor B forward direction control
        self.inB2 = 27   # Motor B backwards direction control

        # Mode of refering to the ports from Raspberry
        GPIO.setmode(GPIO.BCM)

        # Motor A, setting the ports to control the direction of the motor
        GPIO.setup(self.in1,GPIO.OUT)    # Forward
        GPIO.setup(self.in2,GPIO.OUT)    # Backwards

        # Motor B, setting the ports to control the direction of the motor
        GPIO.setup(self.inB1,GPIO.OUT)   # Forward
        GPIO.setup(self.inB2,GPIO.OUT)   # Backwards

        # PWM is output
        GPIO.setup(en,GPIO.OUT)
        GPIO.setup(enb,GPIO.OUT)

        # By default none of the motors should run
        GPIO.output(self.in1,GPIO.LOW)
        GPIO.output(self.in2,GPIO.LOW)
        GPIO.output(self.inB1,GPIO.LOW)
        GPIO.output(self.inB2,GPIO.LOW)

        # PWM on port 25 and 17 with 1000Hz of frequency
        pwm = GPIO.PWM(en,1000)
        pwm2 = GPIO.PWM(enb,1000)

        # On our experiment we will be working around 60% of the PWM, i.e 4.5V applied to the motors
        pwm.start(80)
        pwm2.start(80)
        print("[INFO]: --- Initialized motors from the Robot ---")

        self.pid = pidcontroller.PID(200,300,0)

        # Setting the class variables to be 0 at start and then they will be updated as long the subscriber retrieves them
        self.x = 0
        self.z = 0

        if use_ros:
        # Retrieve the messages over ROS from the position
            rospy.init_node("aruco_receiver")
            self.positionSubscriber = rospy.Subscriber("marker_position", Point, self.positionCallback)
            print("[INFO]: --- Retrieving position from ArUco Marker! ---")

        # [Caso fosse usar Thread] Initializing the Thread
        if use_ros != True:
            self.ArucoInstance = pi_aruco_interface.ArucoInterface()
            # The problem with the thread is because the opening of the camera is concurrent
            self.t = threading.Thread(target=self.ArucoInstance.track_aruco,args=("Thread sendo executada",))

        #self.runTest()
        self.modelIdentification()

    def rotateClockwise(self):
        print("[INFO]: Rotating CW")
        GPIO.output(self.in1,GPIO.LOW)
        GPIO.output(self.in2,GPIO.HIGH)
        # Motor B
        GPIO.output(self.inB1,GPIO.LOW)
        GPIO.output(self.inB2,GPIO.HIGH)

    def rotateCounterClockWise(self):
        print("[INFO]: Rotating CCW")
        # Motor A 
        GPIO.output(self.in1,GPIO.HIGH)
        GPIO.output(self.in2,GPIO.LOW)
        # Motor B
        GPIO.output(self.inB1,GPIO.HIGH)
        GPIO.output(self.inB2,GPIO.LOW)

    def goForward(self):
        print("[INFO]: Robot going forward")
        # Motor A
        GPIO.output(self.in1,GPIO.LOW)
        GPIO.output(self.in2,GPIO.HIGH)
        # Motor B
        GPIO.output(self.inB1,GPIO.HIGH)
        GPIO.output(self.inB2,GPIO.LOW)

    def goBackwards(self):
        print("[INFO]: Robot going backwards")
        # Motor A
        GPIO.output(self.in1,GPIO.HIGH)
        GPIO.output(self.in2,GPIO.LOW)
        # Motor B
        GPIO.output(self.inB1,GPIO.LOW)
        GPIO.output(self.inB2,GPIO.HIGH)
    
    def rotateLeftWheelBackwards(self):
        print("[INFO]: Rotating only the left wheel backwards")
        # Motor A 
        GPIO.output(self.in1,GPIO.HIGH)
        GPIO.output(self.in2,GPIO.LOW)
        # Motor B
        GPIO.output(self.inB1,GPIO.LOW)
        GPIO.output(self.inB2,GPIO.LOW)

    def rotateLeftWheelForward(self):
        print("[INFO]: Rotating only the left wheel forward")
        # Motor A 
        GPIO.output(self.in1,GPIO.LOW)
        GPIO.output(self.in2,GPIO.HIGH)
        # Motor B
        GPIO.output(self.inB1,GPIO.LOW)
        GPIO.output(self.inB2,GPIO.LOW)

    def stopMotors(self):
        print("[INFO]: Stopping both motors")
        GPIO.output(self.in1,GPIO.LOW)
        GPIO.output(self.in2,GPIO.LOW)
        GPIO.output(self.inB1,GPIO.LOW)
        GPIO.output(self.inB2,GPIO.LOW)

    def cleanPorts(self):
        GPIO.cleanup()
        print("[INFO]: GPIO Clean up")
        sys.exit()

    def testMotors(self):
        self.rotateClockwise()
        sleep(5)
        self.rotateCounterClockWise()
        sleep(5)
        self.stopMotors()
        sleep(1)
        self.cleanPorts()

    def pegarPosXCThread(self):
        """ [HALTED] Inicia a thread , i.e a obtencao da posicao"""
        self.t.daemon = True
        self.t.start()
        print(self.ArucoInstance.x)

    def positionCallback(self, position):
        """ Retrieves the ArUco position over ROS """
        self.x = position.x
        self.z = position.z

    def saveMeasurement(self, n, t, x, z):
        n = str(n)
        file = "measurement" + n + ".csv"
        with open(file, mode='w') as measurement:
            measurement = csv.writer(measurement, delimiter=',', quotechar='"', quoting=csv.QUOTE_MINIMAL)
            measurement.writerow(['t', 'x', 'z'])
            for i in range(len(t)):
                measurement.writerow([t[i],x[i],z[i]])

    def followMarker(self):
        """ Pre test function to check if the PID will work. """
        #TODO: Testar pra stop os motores e clean no ctrl+c, ver exemplo do pi aruco interface pois este funciona
        try:
            while True:
                if self.x < -0.05:
                    self.rotateClockwise()
                elif self.x > 0.05:
                    self.rotateCounterClockWise()
                """
                erro = abs(self.x)
                if erro > 0.01:
                    if self.x < -0.05:
                        self.rotateCounterClockWise()
                        while erro > 0.01:
                            new_position = self.x
                            erro = abs(new_position)
                        self.stopMotors
                    if self.x > 0.08:
                        self.rotateClockwise()
                        while erro > 0.01:
                            new_position = self.x
                            erro = abs(new_position)
                        self.stopMotors
                    """
        except(KeyboardInterrupt):
            self.stopMotors
            self.cleanPorts()
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

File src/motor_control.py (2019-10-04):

import RPi.GPIO as GPIO          
from time import sleep

flag=1

# ---- SETTING UP RASPBERRY PI GPIO PORTS! ----- 
en = 25     # PWM port
enb = 17    # PWM2 port

in1 = 24    # Motor A forward direction control
in2 = 23    # Motor A backwards direction control

# Escolhemos duas GPIOs proximas da do Motor A
inB1 = 22   # Motor B forward direction control
inB2 = 27   # Motor B backwards direction control

# Mode of refering to the ports from Raspberry
GPIO.setmode(GPIO.BCM)

# Motor A, setting the ports to control the direction of the motor
GPIO.setup(in1,GPIO.OUT)    # Forward
GPIO.setup(in2,GPIO.OUT)    # Backwards

# Motor B, setting the ports to control the direction of the motor
GPIO.setup(inB1,GPIO.OUT)   # Forward
GPIO.setup(inB2,GPIO.OUT)   # Backwards

# PWM is output
GPIO.setup(en,GPIO.OUT)
GPIO.setup(enb,GPIO.OUT)

# By default none of the motors should run
GPIO.output(in1,GPIO.LOW)
GPIO.output(in2,GPIO.LOW)
GPIO.output(inB1,GPIO.LOW)
GPIO.output(inB2,GPIO.LOW)

# PWM on port 25 with 1000Hz of frequency
pwm = GPIO.PWM(en,1000)
pwm2 = GPIO.PWM(enb,1000)

# Starts PWM with 25%
pwm.start(25)
pwm2.start(25)
print("\n")
print("The default speed & direction of motor is LOW & Forward.....")
print("r-run s-stop f-forward b-backward l-low m-medium h-high e-exit")
print("\n")    

# Infinite loop
while(1):
    x = raw_input()
    
    if x=='r':
        print("Running Motor A")
        if (flag==1):
            # Motor goes forward
            GPIO.output(in1,GPIO.HIGH)
            # We must set then the other direction to low
            GPIO.output(in2,GPIO.LOW)
            print("forward")
            x='z'
        else:
            GPIO.output(in1,GPIO.LOW)
            GPIO.output(in2,GPIO.HIGH)
            print("backward")
            x='z'

    # Adicionei isso pro segundo motor
    elif x=='r2':
        print("Running Motor B")
        if (flag==1):
            # Motor goes forward
            GPIO.output(inB1,GPIO.HIGH)
            # We must set then the other direction to low
            GPIO.output(inB2,GPIO.LOW)
            print("forward motorB")
            x='z'
        else:
            GPIO.output(inB1,GPIO.LOW)
            GPIO.output(inB2,GPIO.HIGH)
            print("backward motor B")
            x='z'

    elif x=='s':
        print("stop")
        GPIO.output(in1,GPIO.LOW)
        GPIO.output(in2,GPIO.LOW)
        GPIO.output(inB1,GPIO.LOW)
        GPIO.output(inB2,GPIO.LOW)
        x='z'

    elif x=='f':
        print("forward")
        GPIO.output(in1,GPIO.LOW)
        GPIO.output(in2,GPIO.HIGH)
        # teste
        GPIO.output(inB1,GPIO.HIGH)
        GPIO.output(inB2,GPIO.LOW)
        flag=1
        x='z'

    elif x=='b':
        print("backward")
        GPIO.output(in1,GPIO.HIGH)
        GPIO.output(in2,GPIO.LOW)
        # teste
        GPIO.output(inB1,GPIO.LOW)
        GPIO.output(inB2,GPIO.HIGH)
        flag=0
        x='z'

    elif x=='m':
        print("medium")
        pwm.ChangeDutyCycle(50)
        pwm2.ChangeDutyCycle(50)
        x='z'

    elif x=='h':
        print("high")
        pwm.ChangeDutyCycle(75)
        pwm2.ChangeDutyCycle(75)
        x='z'
     
    
    elif x=='e':
        GPIO.cleanup()
        print("GPIO Clean up")
        break
    
    else:
        print("<<<  wrong data  >>>")
        print("please enter the defined data to continue.....")

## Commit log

2019-08-07 calibration files
    [calibration.yaml, ros_calibration.yaml]
2019-08-07 Moved calibration files to /src
    [calibration.yaml, ros_calibration.yaml]
2019-08-07 Base for controlling the motor
2019-08-08 added camera checking
2019-08-23 Motor debugging
2019-08-24 3d models from the robot structure
    [MotorRedutor.SLDPRT, SuporteMotor.SLDPRT, SuporteMotor.STL]
2019-08-24 Code for the motor phase test
2019-09-12 list and setorization added
    [MotorRedutor.SLDPRT, SuporteMotor.SLDPRT, SuporteMotor.STL]
2019-09-26 tested motor A and now implemented the code for motor b, needs adjustment
2019-10-04 now operating two motors simultaneouly
2019-10-04 another way to test the motors
2019-10-04 files to measure the robot's velocity
2019-10-05 code to get the speed from the encoder
2019-10-11 adapted code to measure linear velocity in km/h from another source code
2019-10-12 added new parts
    [BaseInferior.DXF, BaseInferior.SLDPRT, TransferidorFinal.DXF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]
2019-10-14 updated new models
    [TransferidorFinal.DXF, TransferidorFinal.SLDPRT]
2019-10-14 adjusted lines to the lase cutter
    [TransferidorFinal.DXF, TransferidorFinal.SLDPRT]
2019-10-18 added new function to test the sensor and adapted the velocity reading with moving average filter
2019-10-30 adjusted the averaging filter to 10 samples and currently working
2019-10-30 code to convert from wheel's speed to robot's speed
2019-10-30 adjusted to calculate from a vector of velocities
2019-11-02 filtered data with plots
    [measurements1.csv]
2019-11-02 chose best measurements and got the experimental curve for the output
    [medicaoJesse4Melhorzinha.csv]
2019-11-03 adapted code to work the JPEG corrupt error around
    [pi_aruco_interface.py, robot_control.py]
2019-11-04 Retrieving position x using generator, currently working on the robot_control
2019-11-05 Added both functionalities with Thread and ROS
2019-11-06 Cleaned the code and currently sending x and z position over ROS, exception handling to close the caption is working as well
2019-11-06 Added function to write the measurements to csv and reading rate is correct (around 45 samples for 1.5s pulse)
    [robot_control.py]
2019-11-07 Added new functions to control the robot, going forward, backwards, rotating only one wheel...
2019-11-08 Functions to control the robot (forward, backwards, only one wheel etc working
2019-11-10 added motor control with Arduino
2019-11-10 Current program used to get the data of our moudel
2019-11-10 Separated the black box modelling between Robot and Wheel, in the end, for the work we needed just the wheel model due to time constraints.
    [inputVelCurve.csv, measurements1.csv, medicaoJesse1.csv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]
2019-11-10 removed left over files
    [measurements1.csv, medicaoJesse4Melhorzinha.csv]
2019-11-11 Levantamos o modeo a 2 e 3 parametros
    [angVel1.csv]
2019-11-11 Code to control the motors along with reading odometry
2019-11-11 Added PID controller, not tested yet
2019-11-11 PID working with the effective working limits
2019-11-12 PID with two different reference points
2019-11-12 Working PID
2019-11-13 PID Working properly
2019-11-13 Final report about the angular velocity control with PID
